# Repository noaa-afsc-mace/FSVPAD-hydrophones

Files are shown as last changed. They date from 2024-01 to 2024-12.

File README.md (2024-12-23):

# FSVPAD

FSVPAD is a free-drifting hydrophone spar buoy designed for measurement of vessel-radiated noise designed for NOAA Fisheries noise-reduced research vessels.

This repository provides processing software, technical information, and example data output from an instrument deployment as described in a NOAA Technical memorandum:

Bassett, C., De Robertis, A., and Gallagher, M. 2024. A passive acoustic drifter for radiated noise measurements of NOAA Fisheries survey vessels. 
U.S. Department of Commerce, NOAA Technical Memorandum NMFS-AFSC-490, 116 p. https://repository.library.noaa.gov/view/noaa/65794

## Primary directories
**Matlab** - contains processing scripts to estimate vessel radiated noise from FSVPAD measurements

**FSVPAD Logger** - python application run on ship-based laptop to collect GPS data and compute the range and bearing between the FSVPAD and the test vessel.

**Technical documentation** - contains technical documentation related to construction and configuration of the FSVPAD system

**Example results** - contains example output of the processing scripts from a 2023 measurement of NOAA ship Oscar Dyson.

# Prerequisites
The analysis scripts require Matlab and the signal processing and statistics toolboxes.

## Authors

* **Chris Bassett** - _Applied Physics Laboratory, University of Washington_ 
* **Alex De Robertis** - _Alaska Fisheries Secience Center, NOAA Fisheries_  

## License

This software is licensed under the GNU License - see the
[LICENSE](LICENSE) file for details

## Acknowledgments

* This work was funded by the National Marine Fisheries Service Office of Science and Technology.

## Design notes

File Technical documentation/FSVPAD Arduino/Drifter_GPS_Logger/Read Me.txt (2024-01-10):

The DrifterGPSLogger code in this directory is the Arduino code that required to log the GPS data. If the Arduino is not operating properly this should be installed on the Arduino unit. Please refer to the manual with any questions about properly loading it.

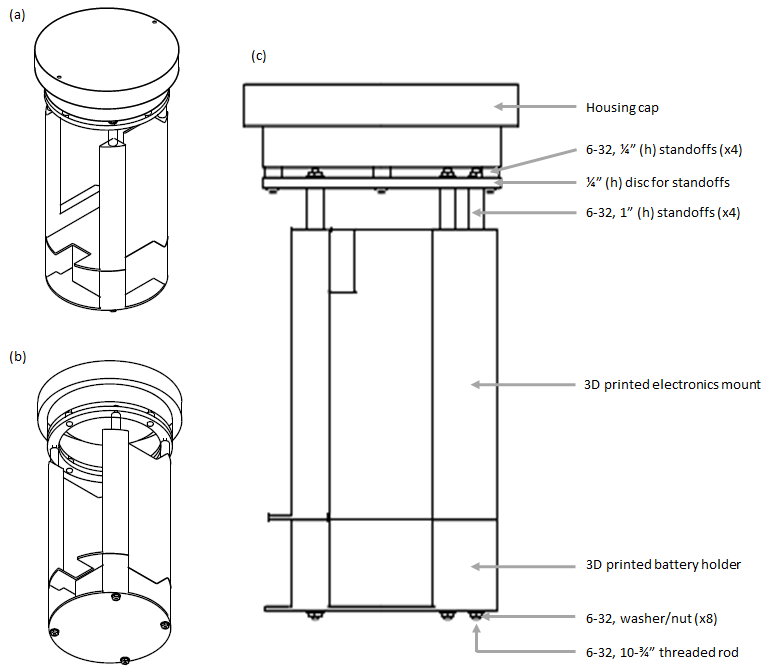
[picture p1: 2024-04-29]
Technical documentation/Subsystemdrawings/Electronics_labels.png

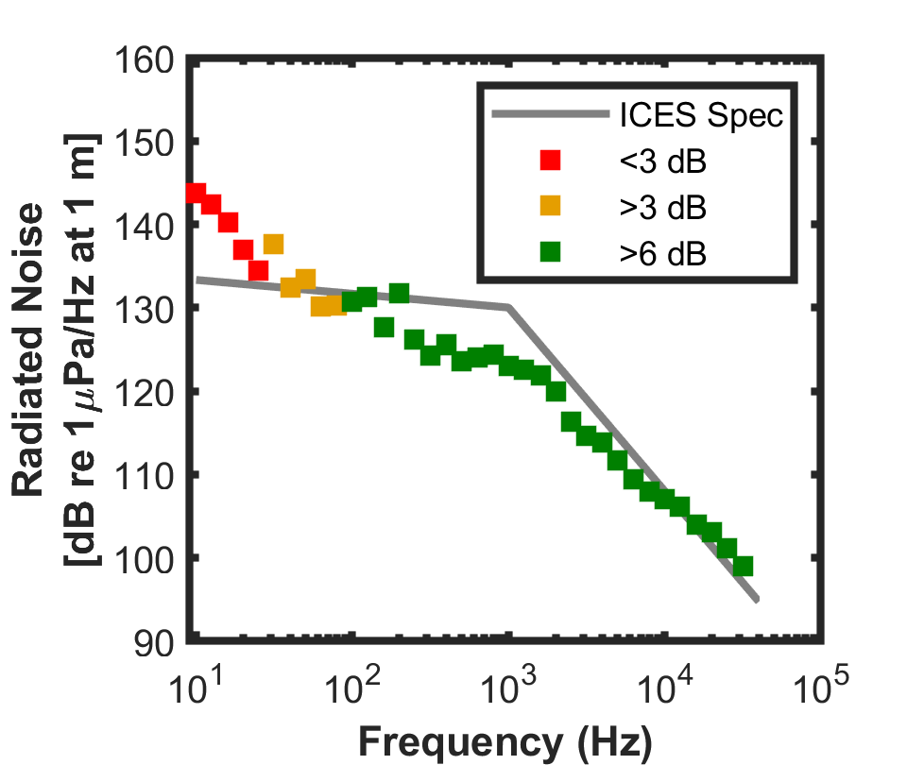
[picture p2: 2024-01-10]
Example results/RadiatedNoise_vs_ICES_Spec.png

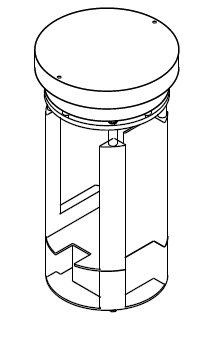
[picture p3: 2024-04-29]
Technical documentation/Subsystemdrawings/Electronics_top.png

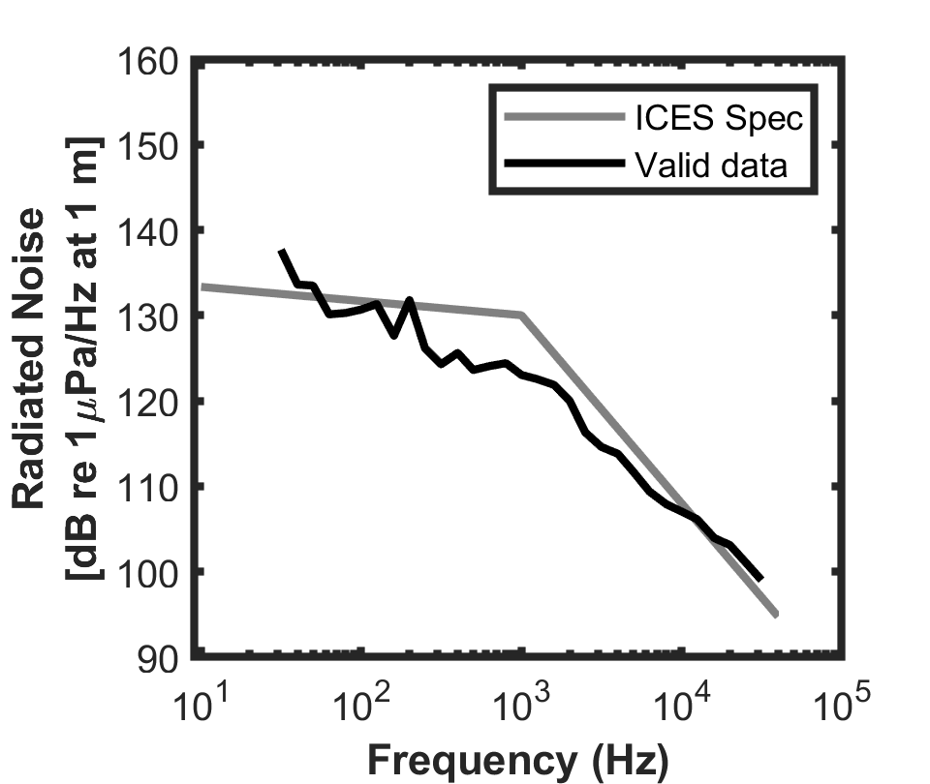
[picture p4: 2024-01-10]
Example results/FORMAL_RadiatedNoise_vs_ICES_Spec.png

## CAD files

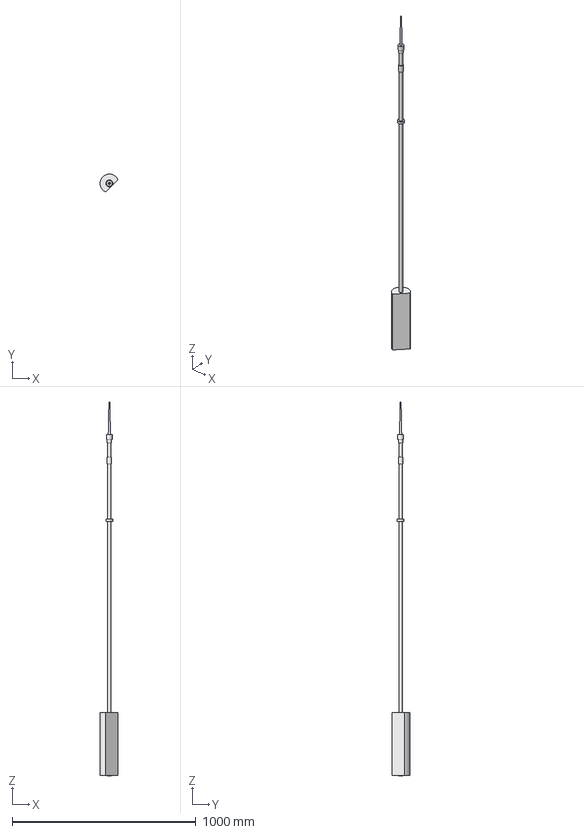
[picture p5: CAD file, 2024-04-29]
Technical documentation/Subsystemdrawings/Antenna_Assembly.FCStd
97.5 x 97.5 x 2037.7 mm

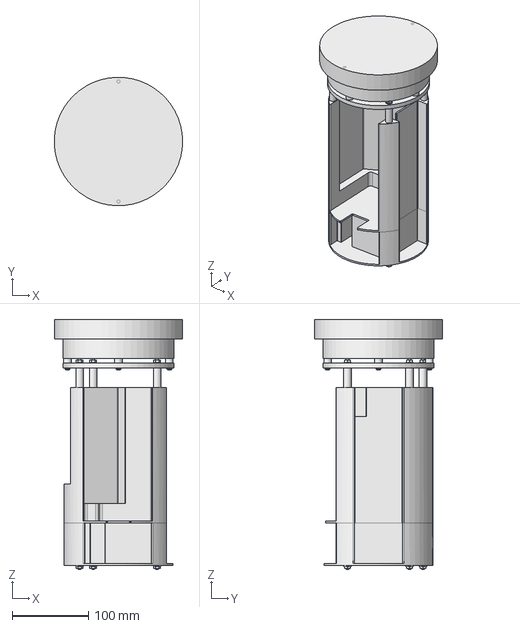
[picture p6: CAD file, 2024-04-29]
Technical documentation/Subsystemdrawings/Electronics_Assembly_Drawings.FCStd
168.1 x 168.2 x 327.7 mm

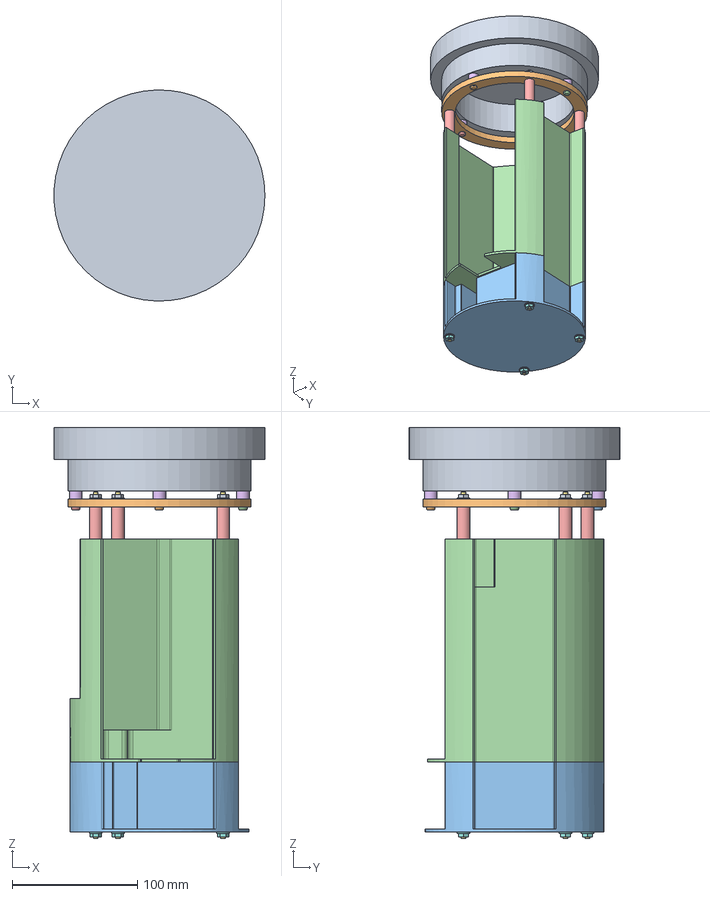
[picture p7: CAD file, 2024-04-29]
Technical documentation/Subsystemdrawings/Electronics_Assembly.FCStd
168.1 x 168.2 x 327.7 mm
Cap
Ring
HousingBottom
HousingTop
BigStandoffs
SmallStandoffs
ThreadedRods
ButtomNuts
TopNuts
Bolt0
Bolt001
Bolt002
Bolt003

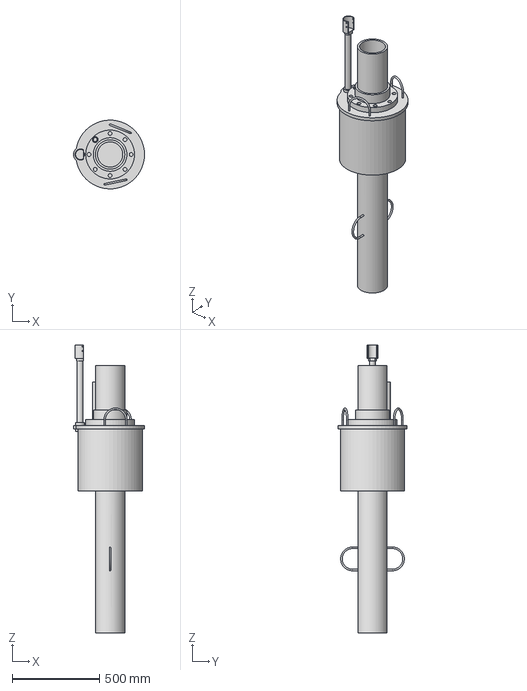
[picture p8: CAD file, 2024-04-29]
Technical documentation/Subsystemdrawings/Spar_Assembly_SinglePart.FCStd
406.4 x 393.4 x 1647.8 mm

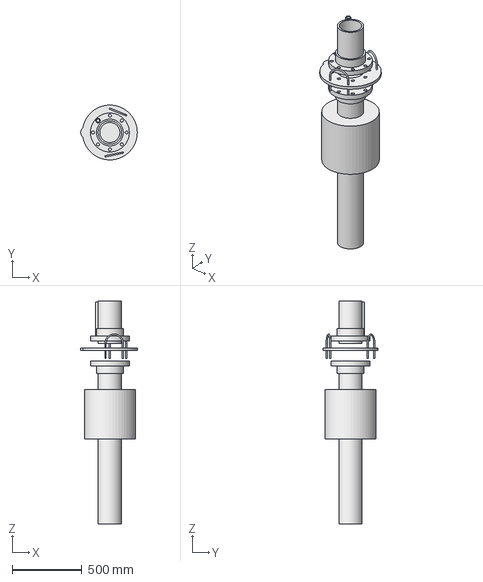
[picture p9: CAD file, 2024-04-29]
Technical documentation/Subsystemdrawings/Exploded_Assembly.FCStd
406.4 x 393.4 x 1600.2 mm

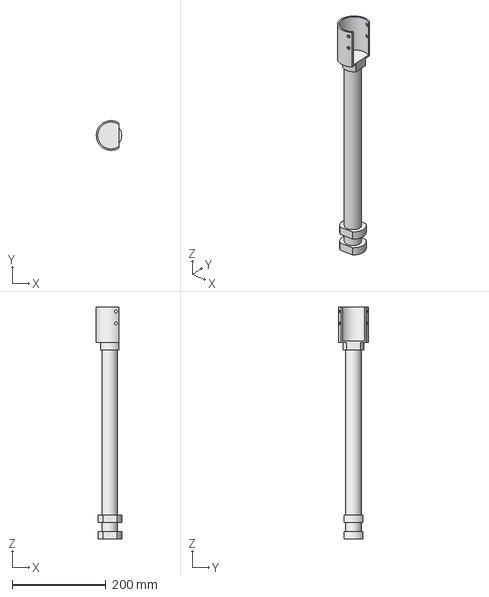
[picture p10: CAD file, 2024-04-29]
Technical documentation/Subsystemdrawings/LightAssembly_wdimensions.FCStd
54.6 x 63.4 x 495.3 mm

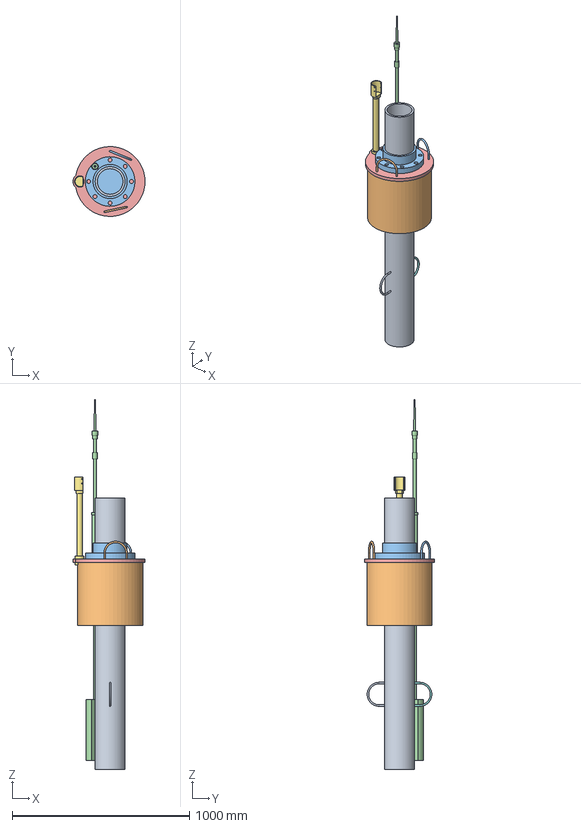
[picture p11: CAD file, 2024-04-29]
Technical documentation/Subsystemdrawings/Spar_Assembly2.FCStd
406.4 x 393.4 x 2086.0 mm
PVC
Flotation
Flange
Collar
Plate
Light
UBolt003
UBolt003 (Mirror #1)
Ubolt1
Ubolt002
Antenna Assembly

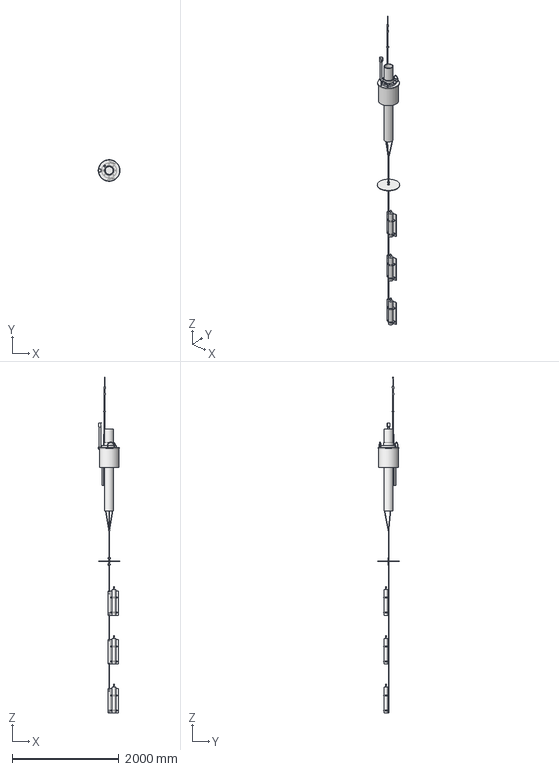
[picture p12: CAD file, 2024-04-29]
Technical documentation/Subsystemdrawings/Full Assembly.FCStd
412.8 x 406.2 x 6289.7 mm

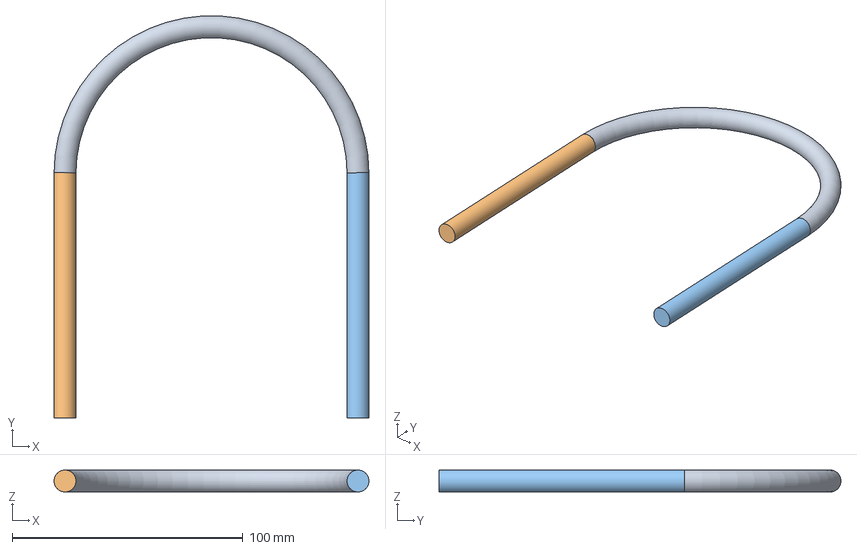
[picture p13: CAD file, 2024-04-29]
Technical documentation/Subsystemdrawings/Spar_Assembly.FCStd
136.5 x 174.3 x 9.52 mm

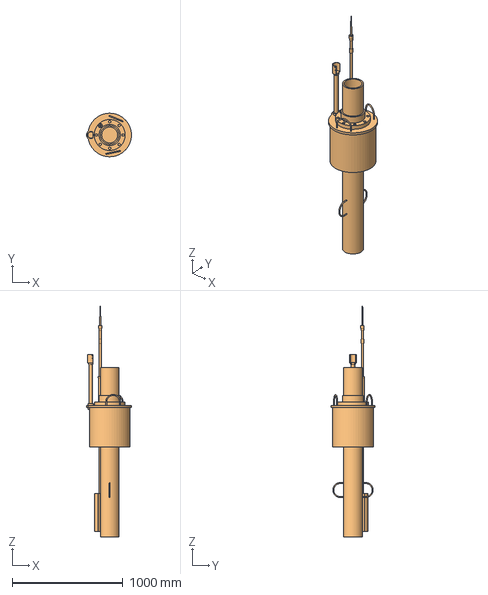
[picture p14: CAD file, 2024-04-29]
Technical documentation/Subsystemdrawings/Spar_Assembly_SinglePart_wAntenna.FCStd
406.4 x 393.4 x 2086.0 mm
UBolt003 (Mirror #1)

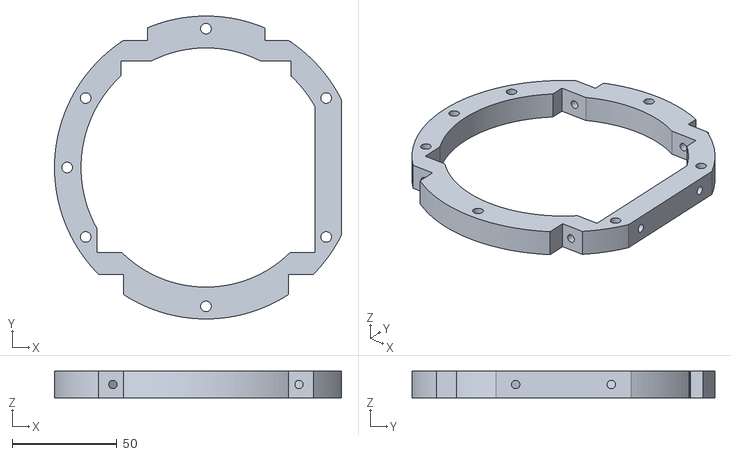
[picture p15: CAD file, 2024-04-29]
Technical documentation/Housingdrawings/GPSTop.stl
137.1 x 144.8 x 12.7

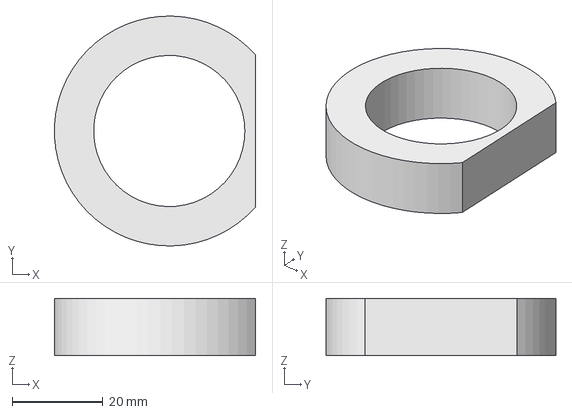
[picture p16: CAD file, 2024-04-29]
Technical documentation/Subsystemdrawings/LightFixtureA.FCStd
44.4 x 50.8 x 12.7 mm

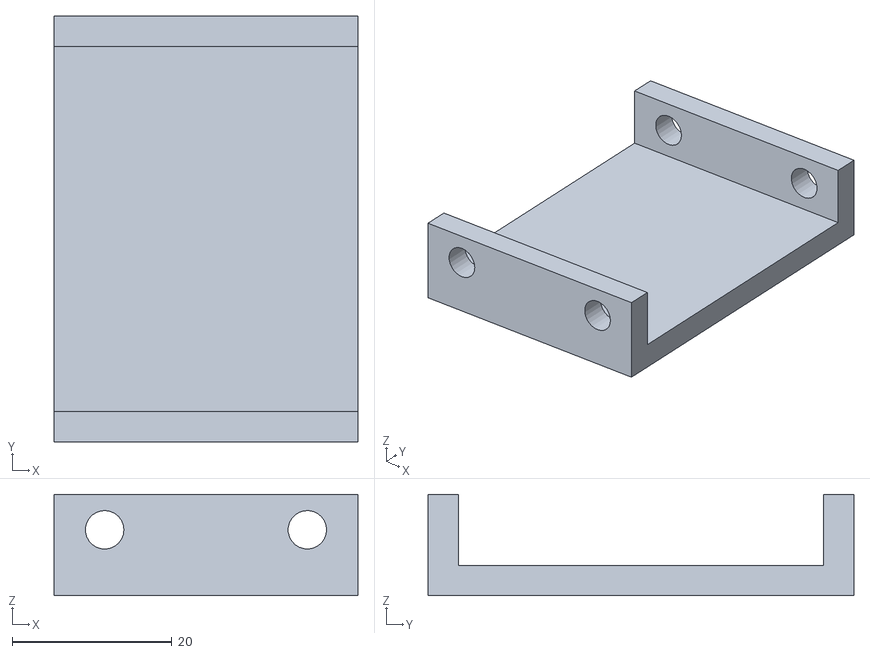
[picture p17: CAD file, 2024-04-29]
Technical documentation/Housingdrawings/Bottom_Holder.stl
38.1 x 53.3 x 12.7

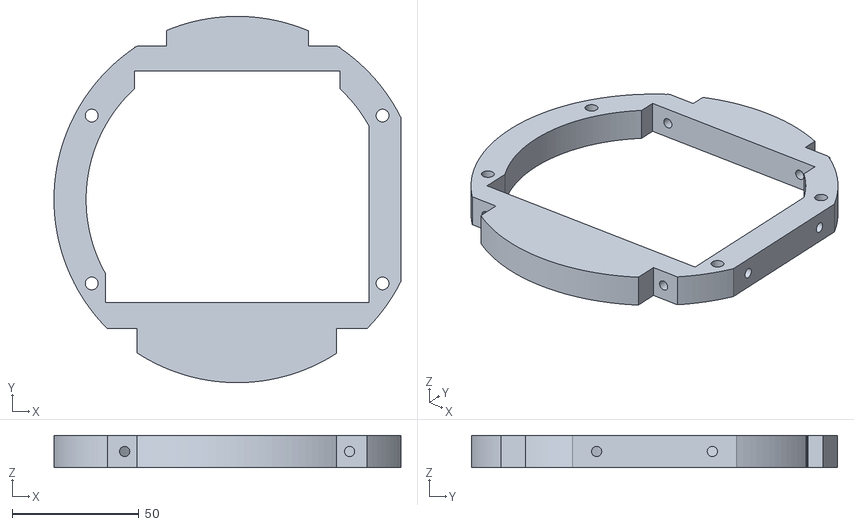
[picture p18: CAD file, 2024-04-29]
Technical documentation/Housingdrawings/Middle.stl
137.1 x 144.8 x 12.7

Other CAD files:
Technical documentation/Subsystemdrawings/LightAssembly.FCStd
Technical documentation/Subsystemdrawings/Strongback_Clamps.FCStd
Technical documentation/Housingdrawings/HousingBot.stl
Technical documentation/Subsystemdrawings/Strongback.FCStd
Technical documentation/Housingdrawings/Top.stl
Technical documentation/Subsystemdrawings/Antenna_PipeFoam.FCStd
Technical documentation/Subsystemdrawings/Antenna_Stopper.FCStd
Technical documentation/Subsystemdrawings/Antenna_Top.FCStd
Technical documentation/Subsystemdrawings/Delrin_Cap.FCStd
Technical documentation/Subsystemdrawings/Exploded with light and antenna.FCStd
Technical documentation/Subsystemdrawings/HeavePlate.FCStd
Technical documentation/Subsystemdrawings/LightFixtureB.FCStd
Technical documentation/Subsystemdrawings/LightFixtureStopper.FCStd
Technical documentation/Subsystemdrawings/MountingPlate.FCStd
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

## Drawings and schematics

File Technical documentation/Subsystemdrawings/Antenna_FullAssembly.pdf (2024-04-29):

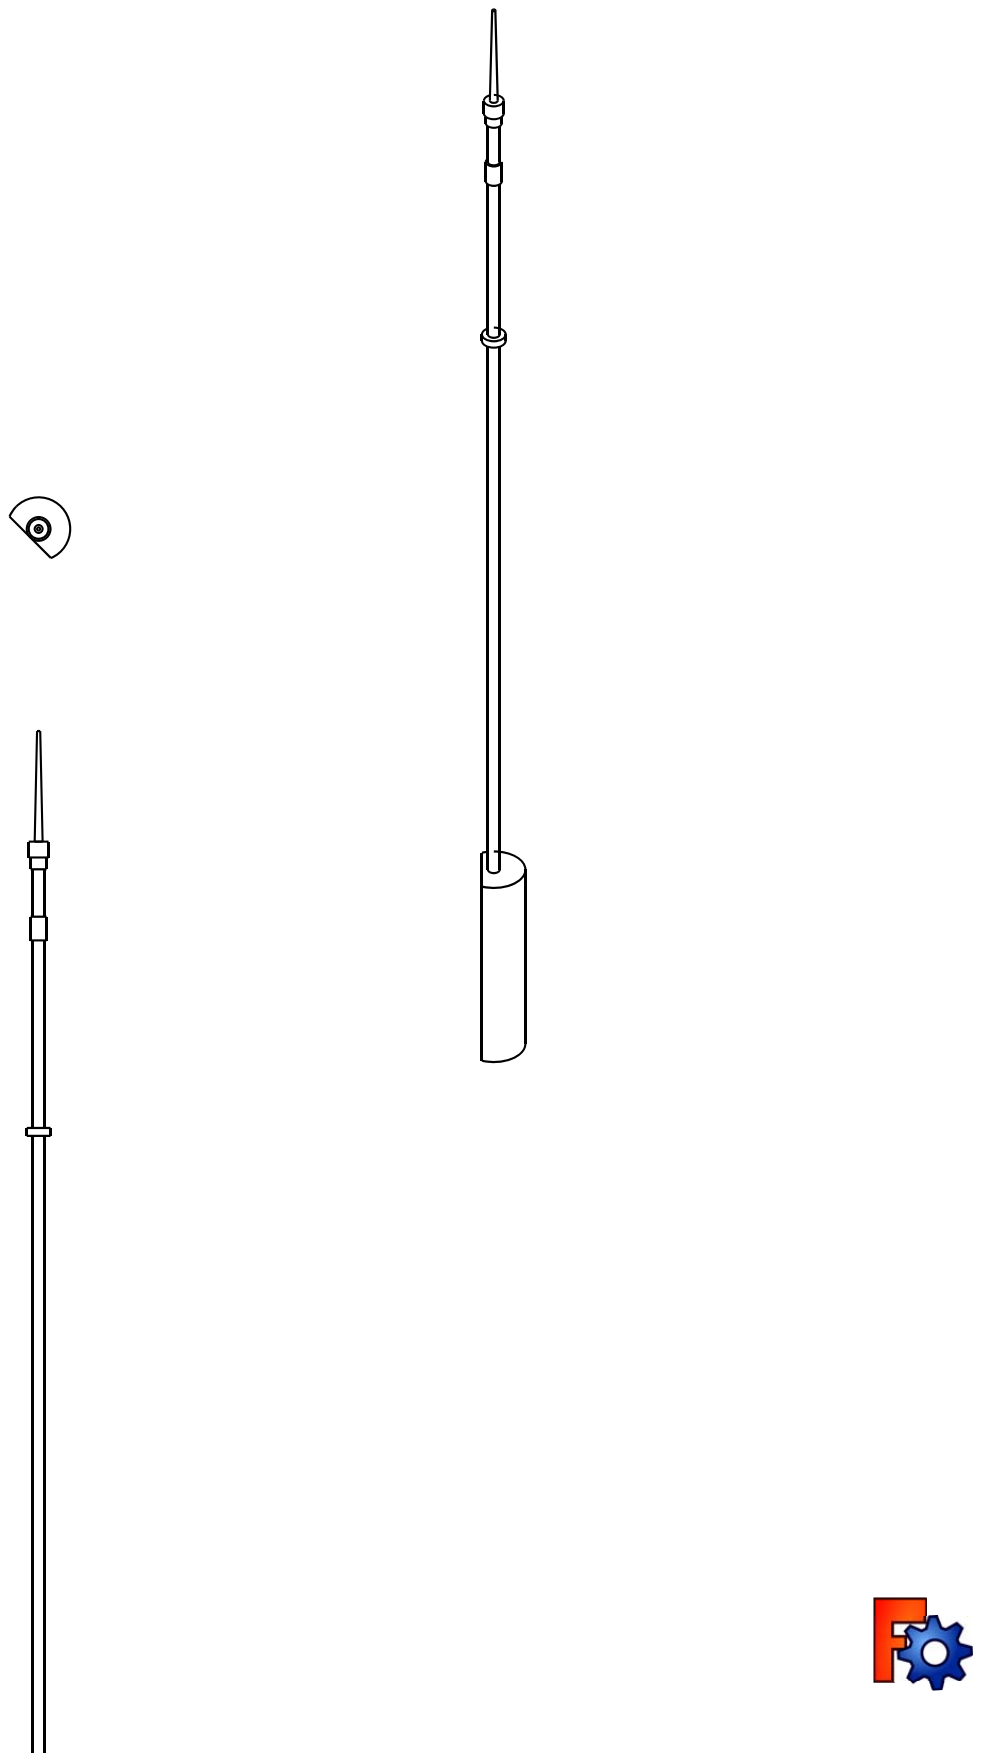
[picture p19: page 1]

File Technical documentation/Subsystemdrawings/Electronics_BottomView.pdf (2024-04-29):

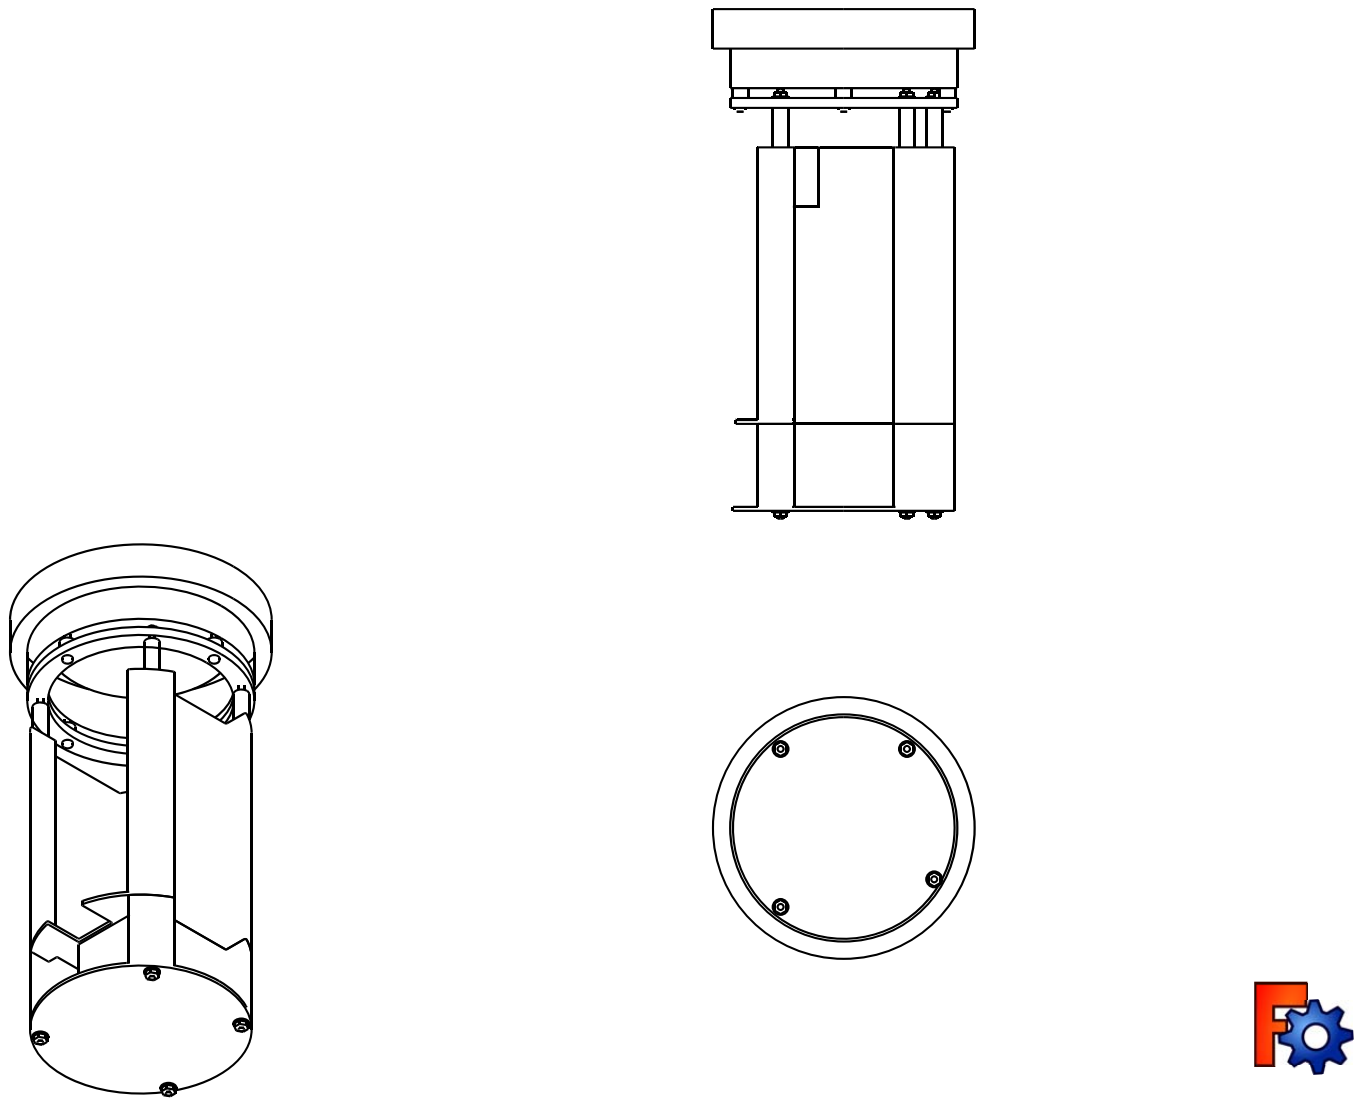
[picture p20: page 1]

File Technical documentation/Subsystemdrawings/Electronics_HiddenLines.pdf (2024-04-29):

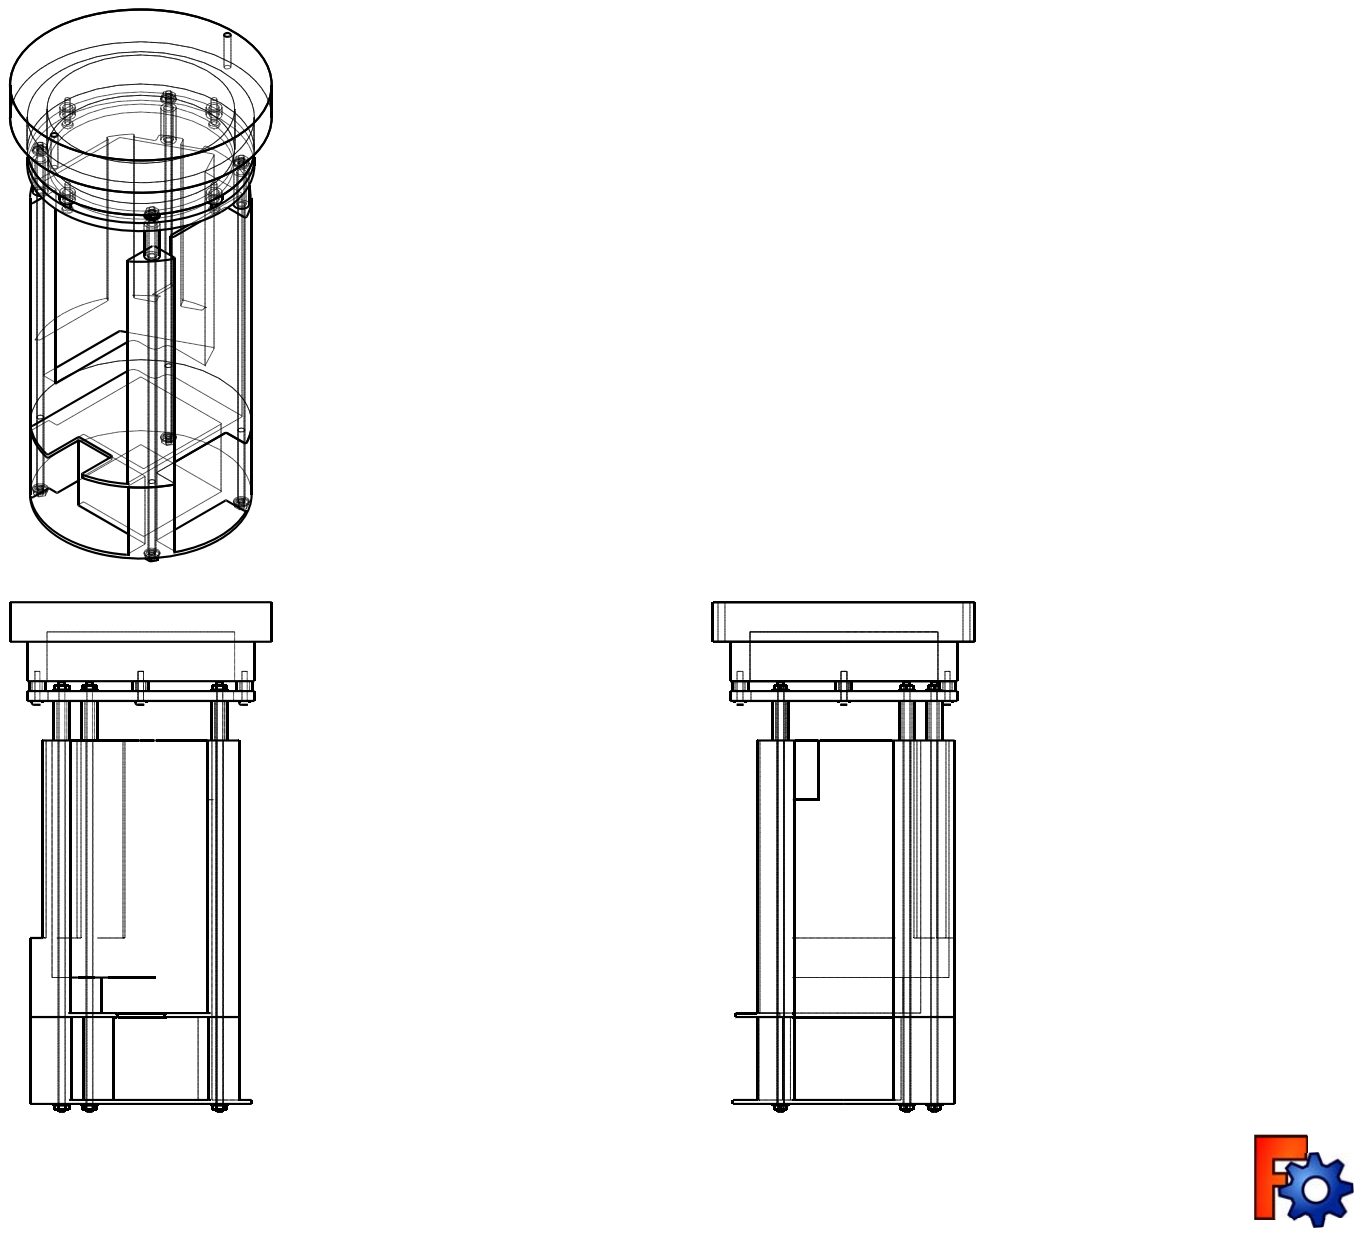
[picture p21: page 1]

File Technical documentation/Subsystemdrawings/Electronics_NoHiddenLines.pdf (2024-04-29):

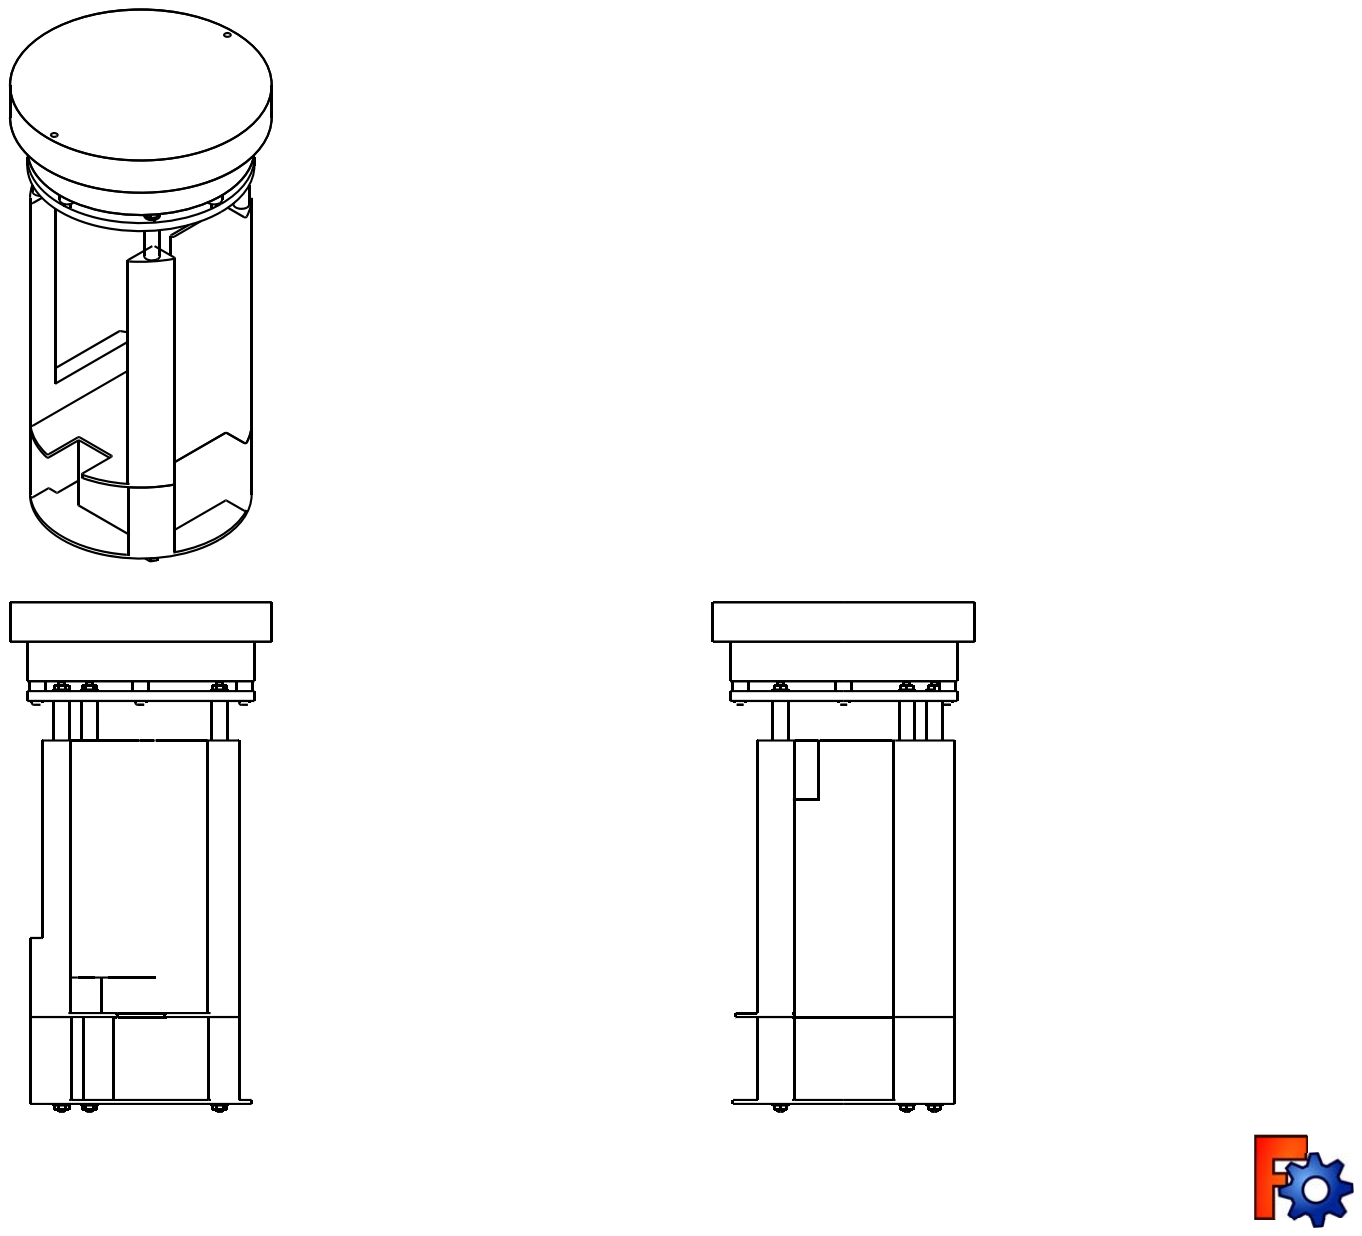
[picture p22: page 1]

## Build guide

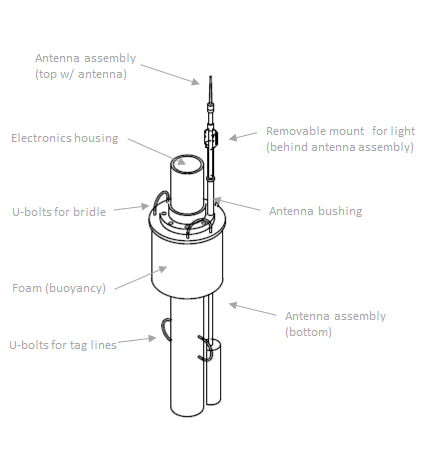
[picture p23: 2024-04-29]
Technical documentation/Subsystemdrawings/Spar Assembly w labels.png

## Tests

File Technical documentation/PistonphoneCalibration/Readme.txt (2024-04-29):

Pistonphone calibration results from an example benchtop calibration.
Data processed using the Matlab post-processing scripts

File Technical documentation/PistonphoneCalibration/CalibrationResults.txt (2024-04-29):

BAD CAL: Hydrophone 382278 (-164.3 dB re 1V/uPa) - Calibration Signal: 142.8 dB re 1 uPa
BAD CAL: Hydrophone 382293 (-164.0 dB re 1V/uPa) - Calibration Signal: 146.3 dB re 1 uPa
BAD CAL: Hydrophone 382295 (-164.5 dB re 1V/uPa) - Calibration Signal: 147.3 dB re 1 uPa
GOOD CAL: Hydrophone 382314 (-163.8 dB re 1V/uPa) - Calibration Signal: 144.3 dB re 1 uPa
GOOD CAL: Hydrophone 382299 (-164.6 dB re 1V/uPa) - Calibration Signal: 144.6 dB re 1 uPa
BAD CAL: Hydrophone 382313 (-163.4 dB re 1V/uPa) - Calibration Signal: 145.8 dB re 1 uPa

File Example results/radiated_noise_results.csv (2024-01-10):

Frequency | ICES_209_SL | Bandwidth | TOL_SPL_RAW | TOL_SPL_3dB_SNR | SL_relative_to_ICES | SNR_shallow | SNR_middle | SNR_deep | num_hyds_used_SNR3dB | index_all_hyds_SNR6dB | SPL_pass1 | SPL_pass2 | SPL_pass3 | SPL_pass4 | SPL_pass5 | SPL_pass6
10 | 133.34 | 2.31563330169034 | 143.721614166678 | NaN | NaN | -1.31784918895962 | 1.1500093296291 | 2.49998898340603 | 0 | 0 | NaN | NaN | NaN | NaN | NaN | NaN
12.5 | 133.179129378407 | 2.89454162711292 | 142.406826937904 | NaN | NaN | 0.115016953940292 | -0.893792906320099 | 2.69424850618762 | 0 | 0 | NaN | NaN | NaN | NaN | NaN | NaN
16 | 133.001160828791 | 3.70501328270454 | 140.222246034424 | NaN | NaN | 0.759748627877375 | 0.933404089470426 | 3.56683204120338 | 1 | 0 | 144.995058425381 | 141.654688384133 | 143.500385734567 | 142.166243581038 | 143.688646832846 | 143.298113300334
20 | 132.840290207198 | 4.63126660338067 | 136.911014351441 | NaN | NaN | -0.580436775852897 | 1.02969898046016 | 2.58411550399341 | 0 | 0 | NaN | NaN | NaN | NaN | NaN | NaN
25 | 132.679419585604 | 5.78908325422584 | 134.473093325679 | NaN | NaN | 1.27976656151581 | 0.298605808923091 | 2.60855366783743 | 0 | 0 | NaN | NaN | NaN | NaN | NaN | NaN
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

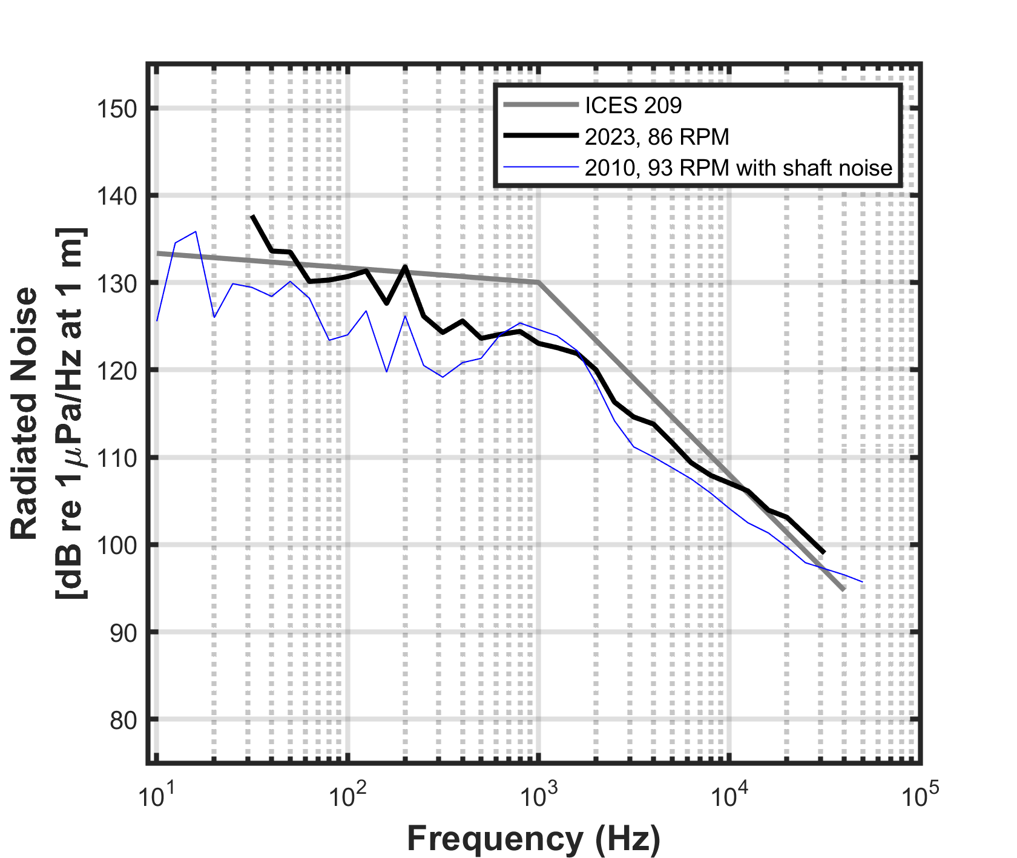
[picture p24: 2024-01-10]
Example results/DY_2023_and_2010_shaft_noise_comparison.png

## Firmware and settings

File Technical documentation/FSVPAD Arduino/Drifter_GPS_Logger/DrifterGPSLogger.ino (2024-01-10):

// Ladyada's logger modified by Chris Bassett
// for logging spar buoy GPS data

#include <SD.h>
#include "GPSconfig.h"
#include <SoftwareSerial.h>


// power saving modes
#define TURNOFFGPS 0    /* set to 1 to enable powerdown of arduino and GPS. Ignored if SLEEPDELAY == 0 */
#define LOG_RMC_FIXONLY 0  /* set to 1 to only log to SD when GPD has a fix */

// what to log
#define LOG_RMC 1 // RMC-Recommended Minimum Specific GNSS Data, message 103,04
//#define LOG_GGA 0 // GGA-Global Positioning System Fixed Data, message 103,00
//#define LOG_GLL 0 // GLL-Geographic Position-Latitude/Longitude, message 103,01
//#define LOG_GSA 0 // GSA-GNSS DOP and Active Satellites, message 103,02
//#define LOG_GSV 0 // GSV-GNSS Satellites in View, message 103,03
//#define LOG_VTG 0 // VTG-Course Over Ground and Ground Speed, message 103,05

// Use pins 2 and 3 to talk to the GPS. 2 is the TX pin, 3 is the RX pin
 SoftwareSerial gpsSerial =  SoftwareSerial(2, 3);
// Set the GPSRATE to the baud rate of the GPS module. Most are 4800
// but some are 38400 or other. Check the datasheet!
#define GPSRATE 4800

// Set the pins used 
//#define powerPin 4
#define ledPin1 6
#define ledPin2 5
#define chipSelect 10


#define BUFFSIZE 90
char buffer[BUFFSIZE];
uint8_t bufferidx = 0;
bool fix = false; // current fix data
bool gotGPRMC;    //true if current data is a GPRMC strinng
uint8_t i;
int pinState2 = HIGH;

//SdFat SD;

File logfile;

// read a Hex value and return the decimal equivalent
uint8_t parseHex(char c) {
  if (c < '0')
    return 0;
  if (c <= '9')
    return c - '0';
  if (c < 'A')
    return 0;
  if (c <= 'F')
    return (c - 'A')+10;
}

// blink out an error code


void setup() {
  WDTCSR |= (1 << WDCE) | (1 << WDE);
  WDTCSR = 0;
  //Serial.begin(9600);
  //Serial.println("\r\nGPSlogger");
  pinMode(ledPin1, OUTPUT);
  pinMode(ledPin2, OUTPUT);

  // make sure that the default chip select pin is set to
  // output, even if you don't use it:
  pinMode(chipSelect, OUTPUT);
  strcpy(buffer, "DGPS000.TXT");

  //pinMode(powerPin, OUTPUT);
  //digitalWrite(powerPin, LOW);

  
  // see if the card is present and can be initialized:
  if (!SD.begin(chipSelect)) {
      //Serial.println("Card init. failed!");
        for (i=0; i<120; i++) {
         digitalWrite(ledPin1, HIGH);
         digitalWrite(ledPin2, LOW);
         delay(250);
         digitalWrite(ledPin1, LOW);
         digitalWrite(ledPin2, LOW);
         delay(250);  
      };
  }

    for (i = 0; i < 1000; i++) {
      buffer[4] = '0' + i/100;
      buffer[5] = '0' + i/10;
      buffer[6] = '0' + i%10;      
        // create if does not exist, do not open existing, write, sync after write
      if (! SD.exists(buffer)) {
        break;
    }
    }

  logfile = SD.open(buffer, FILE_WRITE);
  if( ! logfile ) {
    //Serial.print("Couldnt create "); Serial.println(buffer);
          for (uint8_t i = 0; i < 15; i++) {
          // Red slow blinking
          digitalWrite(ledPin1, HIGH);
          digitalWrite(ledPin2, LOW);
          delay(3000);
          digitalWrite(ledPin1, LOW);
          digitalWrite(ledPin2, LOW);
          delay(1000);  
       };
  }
  //Serial.print("Writing to "); Serial.println(buffer);
  
  // connect to the GPS at the desired rate
  gpsSerial.begin(GPSRATE);
  
  //Serial.println("Ready!");
  
  gpsSerial.print(SERIAL_SET);

#if (LOG_RMC == 1)
    gpsSerial.print(RMC_ON);
#else
    gpsSerial.print(RMC_OFF);
#endif

}

void loop() {
  //Serial.println(Serial.available(), DEC);
  char c;
  uint8_t sum;

  // read one 'line'
  if (gpsSerial.available()) {
    c = gpsSerial.read();

    if (bufferidx == 0) {
      while (c != '$')
        c = gpsSerial.read(); // wait till we get a $
    }
    buffer[bufferidx] = c;


    //Serial.print(c, BYTE);

    if (c == '\n') {
      //putstring_nl("EOL");
      //Serial.print(buffer);
      buffer[bufferidx+1] = 0; // terminate it

      if (buffer[bufferidx-4] != '*') {
        // no checksum?
        //Serial.print('*');
        bufferidx = 0;
        return;
      }
      // get checksum
      sum = parseHex(buffer[bufferidx-3]) * 16;
      sum += parseHex(buffer[bufferidx-2]);

      // check checksum
      for (i=1; i < (bufferidx-4); i++) {
        sum ^= buffer[i];
      }
      if (sum != 0) {
        //putstring_nl("Cxsum mismatch");
        //Serial.print('~');
        bufferidx = 0;
        return;
      }
      // got good data!

      gotGPRMC = strstr(buffer, "GPRMC");
//      if (gotGPRMC) {
//        // find out if we got a fix
//        char *p = buffer;
//        p = strchr(p, ',')+1;
//        p = strchr(p, ',')+1;       // skip to 3rd item
//        
//        if (p[0] == 'V') {
//          digitalWrite(ledPin2, LOW);
//          fix = false;
//        } else {
//          digitalWrite(ledPin2, HIGH);
//          fix = true;
//        }
//      }
//      if (LOG_RMC_FIXONLY) {
//        if (!fix) {
//          //Serial.print('_');
//          bufferidx = 0;
//          return;
//        }
//      }
      // rad. lets log it!
      
      
      if (gotGPRMC)      //If we have a GPRMC string
      {
        // Bill Greiman - need to write bufferidx + 1 bytes to getCR/LF
        bufferidx++;
      //Serial.print(buffer);    //first, write it to the serial monitor

      if (pinState2 == LOW){
          pinState2 = HIGH;
      }
      else{  
            pinState2 = LOW;
      }
       digitalWrite(ledPin2, pinState2);


        logfile.write((uint8_t *) buffer, bufferidx);    //write the string to the SD file
        logfile.flush();
        /*
        if( != bufferidx) {
           putstring_nl("can't write!");
           error(4);
        }
        */


        bufferidx = 0;    //reset buffer pointer

        
        return;
      }
      
    }
    bufferidx++;
    if (bufferidx == BUFFSIZE-1) {
       //Serial.print('!');
       bufferidx = 0;
    }
  } 

}



/* End code */

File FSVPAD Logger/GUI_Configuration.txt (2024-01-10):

[drifter]
com_port: 11
com_baud: 4800

[ship]
com_port: 19
com_baud: 4800

[logging]
directory: C:\Users\MACE\Documents\DrifterData

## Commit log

2024-01-10 Adding processing code and example results files
    [radiated_noise_results.csv]
2024-01-10 Adding FSVPAD logger software to repo
    [GUI_Configuration.txt]
